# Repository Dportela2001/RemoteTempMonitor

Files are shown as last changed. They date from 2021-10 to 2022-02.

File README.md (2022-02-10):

# RemoteTempMonitor :beers:
Equipo:
 - Diego Alejandro Figueroa del Castillo
 - Danny Esteban Portela Robayo
 - Omar Andrés Cely Villate

Dispositivo embebido enfocado a monitorear y guiar al usuario en la creación de cerveza. Se pretende que el dispositivo funcione como una herramienta de ayuda que pueda facilitar la toma de temperatura, y el subsecuente control de la misma en las fáses de calentamiento y enfriamiento del mosto.

## Descripción no funcional

- Acoplarse adecuadamente al recipiente empleado.
- Comunicarse de manera inalámbrica via Wifi o bluetooth. 
- Tener una resolución de 1°C con incertidumbre de  0.5°C.
- Medir temperaturas entre: 0ºC a 120ºC. 
- Establecer conexiones a mínimo 10 m de distancia.
- Tener un tiempo de comunicación de 15s.

## Descripción funcional 

- Medir temperatura.
- Enviar la temperatura a un dispositivo móvil .
- Permitir la configuración de alarmas de temperatura.
- Disparar alarmas. 
- Mostrar temperatura en un display.

## Fases de la utilización del producto:

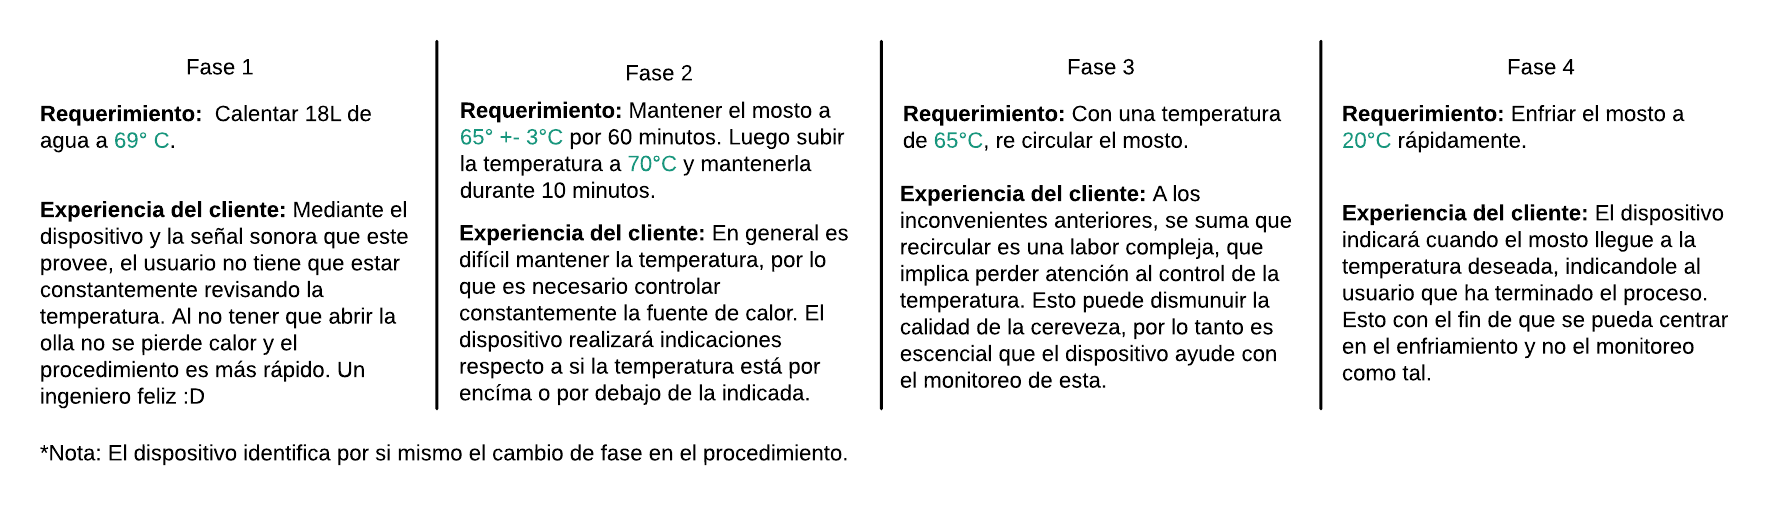
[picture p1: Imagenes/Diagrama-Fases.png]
Fases


## Diagrama de bloques de la solución

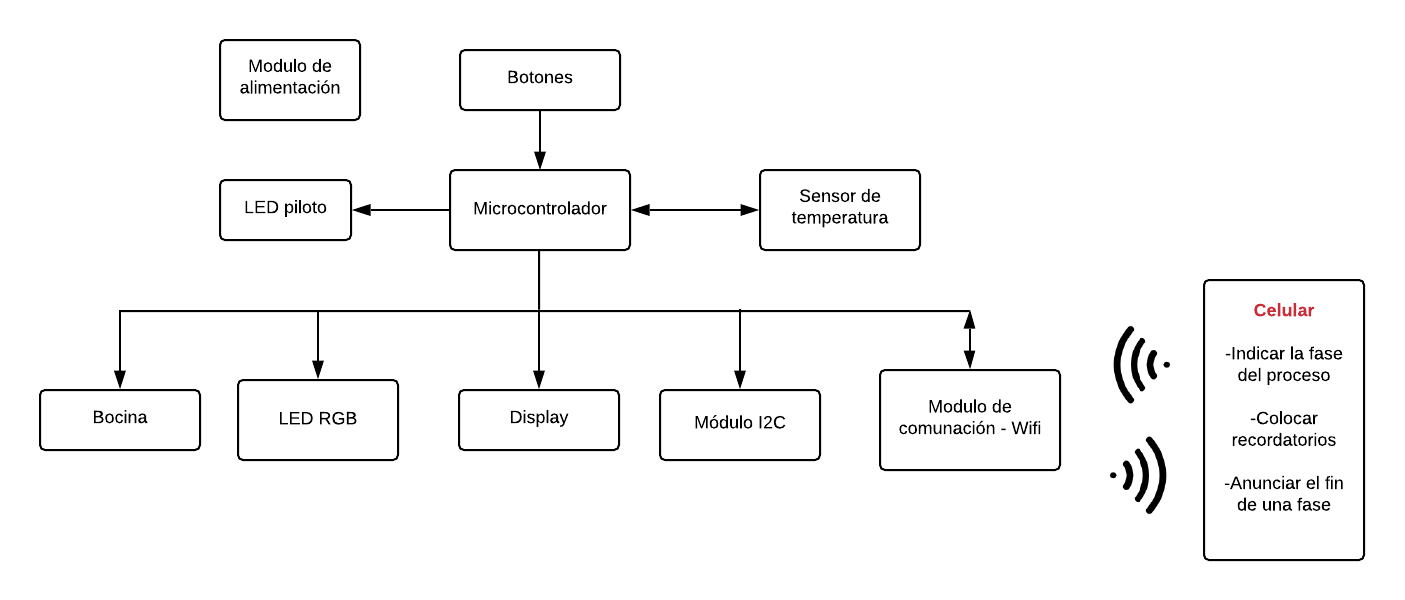
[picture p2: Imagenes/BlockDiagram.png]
Bloques


## Dispositivos a emplear :page_facing_up:
A continuación se ve una lista resumida de los elementos más importantes a utilizar, con sus respectivos precios, cantidad y tienda sugerida, para una lista más detallada de todos los componentes puede ver el excel [**Lista_componentes.xlsx**](/Lista_componentes.xlsx).

# [Diseño de la pcb](/CircuitDesign):bulb:

Para llevar a cabo el diseño del circuito embebido, se empleó el programa open source Kikad, donde todos los archivos generados se encuentran en la carpeta **CircuitDesign**, en donde se encuentran dos versiones de la placa. La primera empleando vias para conectar la cara superior con la inferior, que se ve en la carpeta **PCB_Design**. Sin embargo, debido a las limitaciones de tiempo y capacidades de realización fue necesario realizar una modificación cambiando las vias por conexiones mediante pines. Este segundo diseño se encuentra en **PCB_Design_Low_Cost**

## Zona de potencia
Como todo circuito electrónico, se requiere de una fuente de potencia para el funcionamiento del mismo. Para esto se planteó fos bloques principales, uno para la regulación de voltage que llega a la ESP32 y sus periféricos, y un bloque de carga para las baterías que alimentan el conjunto. Dichos bloques son:

<p align="center">
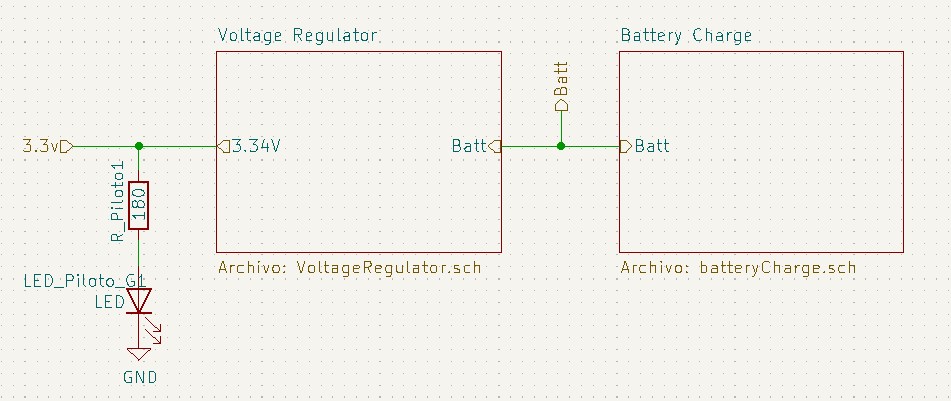
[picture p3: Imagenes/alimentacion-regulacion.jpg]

</p>
  
## Regulador de Voltaje
Dado que la tensión que entregan las baterías de Litio es de 4.2V, es necesario agregar el integrado MIC37303YME, que permite entregar la tensión deseada de 3.3v a la entrada de la ESP32. El esquemático empleado es el siguiente:

<p align="center">
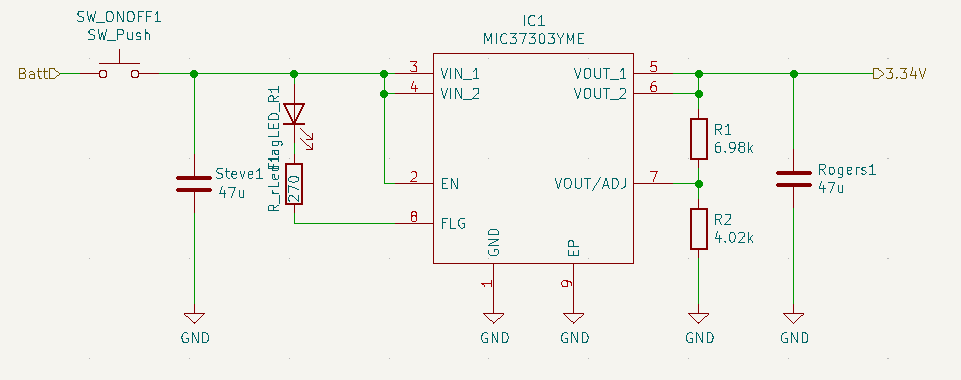
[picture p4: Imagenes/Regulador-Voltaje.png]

</p>

## Cargador de Baterías 

Evidentemente las baterias empleadas requieren ser cargadas de vez en cuando para que el sistema funcione. Por ello se agregó el integrado TP4056 con el circuito de la imagen, para realizar esta operación y así mismo proveer de leds guía de cargado y descargado.

<p align="center">
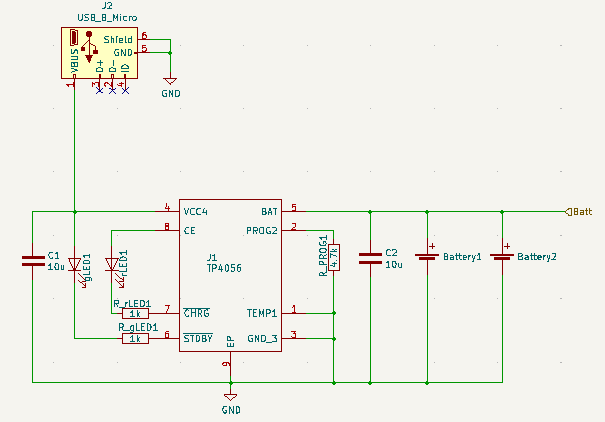
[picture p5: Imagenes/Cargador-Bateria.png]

</p>

Para conveniencia del usuario, se decidió agregar un conector tipo micro-usb B como conector para realizar la carga del dispositivo. Además cuando el dispositivo está sin carga se indicará con un led rojo como se observa a continuación:

<p align="center">
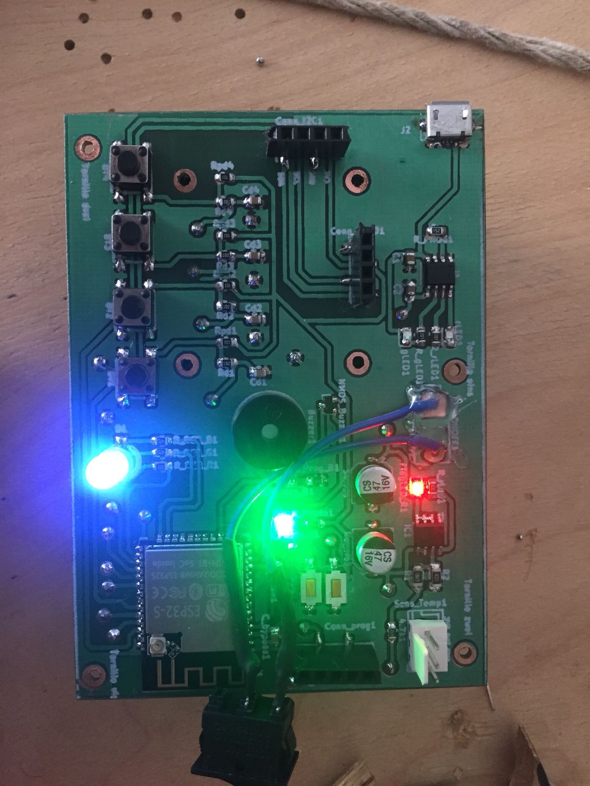
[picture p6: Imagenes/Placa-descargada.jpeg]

</p>
  
En caso de que se haya completado la carga, el indicador resultante es: 

<p align="center">
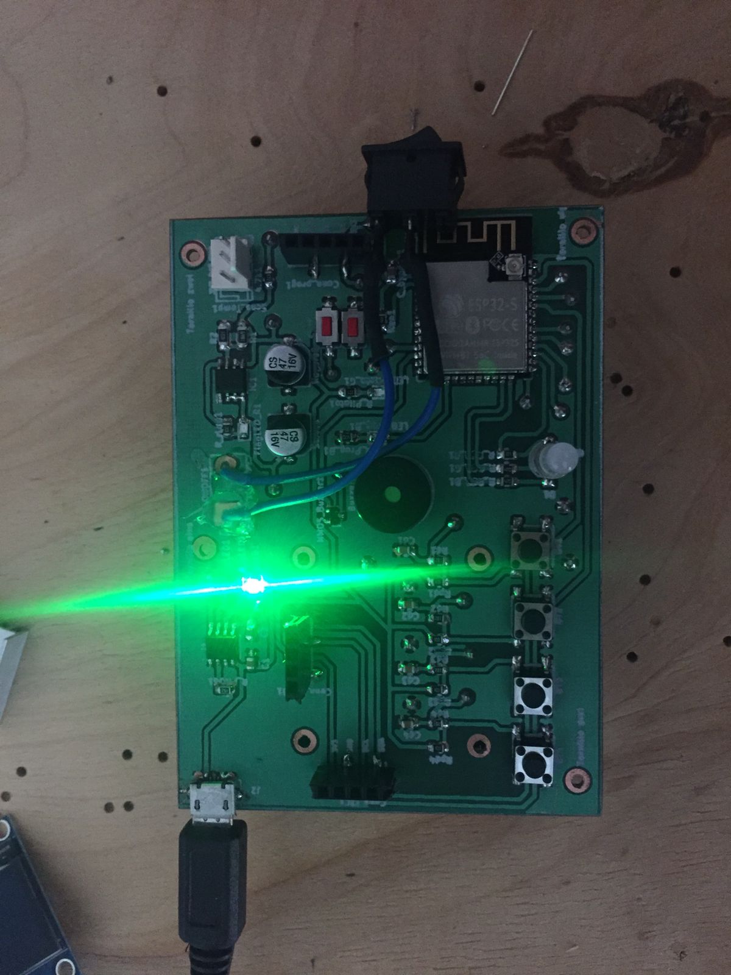
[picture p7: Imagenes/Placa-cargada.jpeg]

</p>

## Esquemático ESP32

El microprocesador empleado para el proyecto es la ESP32 standalone, que posee una flexibilidad y robustez más que suficiente para los propócitos del mismo. Es posible emplear toda la gama de pines GPIO dependiendo de la necesidad, por ejemplo para lectura o escritura. El esquemático resultante es:

<p align="center">
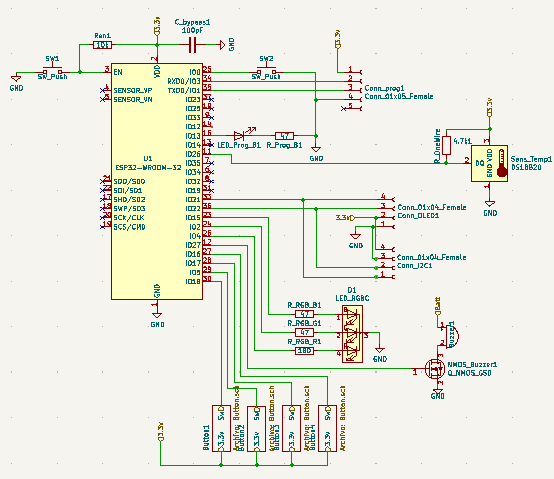
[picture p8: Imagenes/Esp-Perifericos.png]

</p>

Es posible entonces realizar el diseño de la PCB y el ruteo de los caminos  para generar los archivos gerber y enviarlos a impresión en un local dedicado a esta labor. El sieño obtenido finalmente después de añadir además las conexiones entre capas es:

<p align="center">
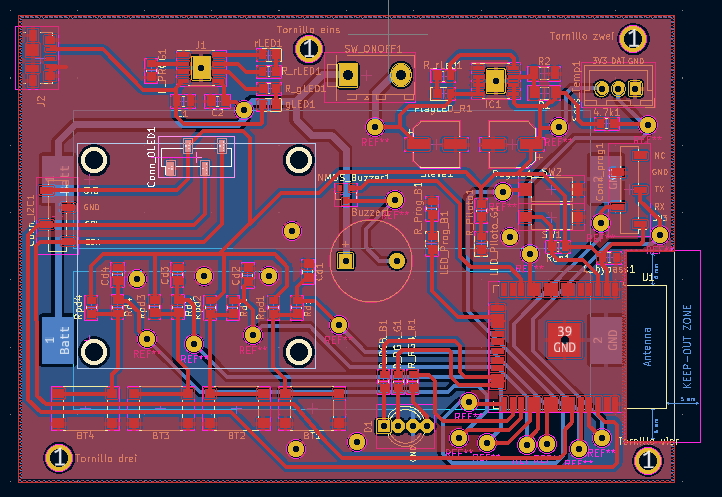
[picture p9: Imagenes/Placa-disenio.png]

</p>

# [Software del dispositivo](/Micropython):snake: 

Para poder programar el microprocesador ESP32 se optó por usar el lenguaje **MicroPython**, por su facilidad de sintaxis, versatilidad y cantidad de librerias disponibles para facilitar el proceso de codificación. Algunas de las librerías empleadas son:

- SH1106 (librería para controlar la pantalla OLED, extraida de: https://github.com/robert-hh/SH1106)
- DS18B20 (librería para controlar la sonda de temperatura, ya presente en Micropython)

Para ver en detalle el código empleado para el funcionamiento del termómetro se puede revisar la carpeta **Micropython** en la rama principal.
Además, se empleó el programa _Mu_ para escribir y subir el código de Micropython directamente a la memoria del ESP32. Otra ventaja de este lenguaje se hace evidente en cuanto a que su subida es veloz al microprocesador, ya que el proceso de compilado del colido ocurre precisamente en este.

## Distintas instancias del programa del proyecto

El programa diseñado para el dispositivo posee distintas instancias tanto de configuración como de funcionamiento, que se encuentran en las siguientes imagenes: 
<table>
  <tr>
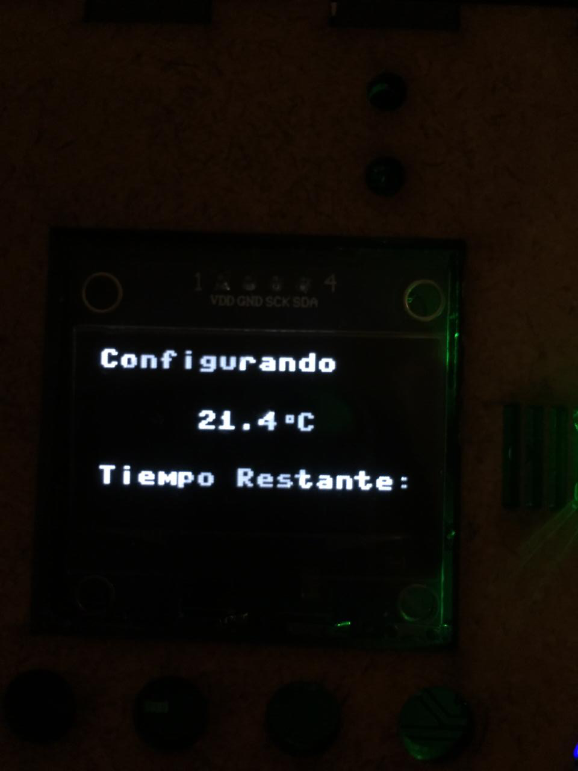
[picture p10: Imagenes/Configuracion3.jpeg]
      <td></td>
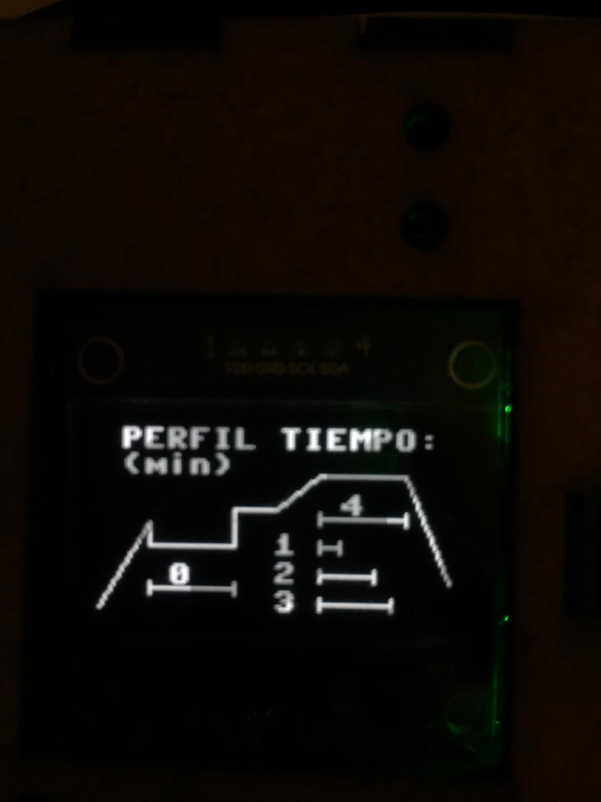
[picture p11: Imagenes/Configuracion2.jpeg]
      <td></td>
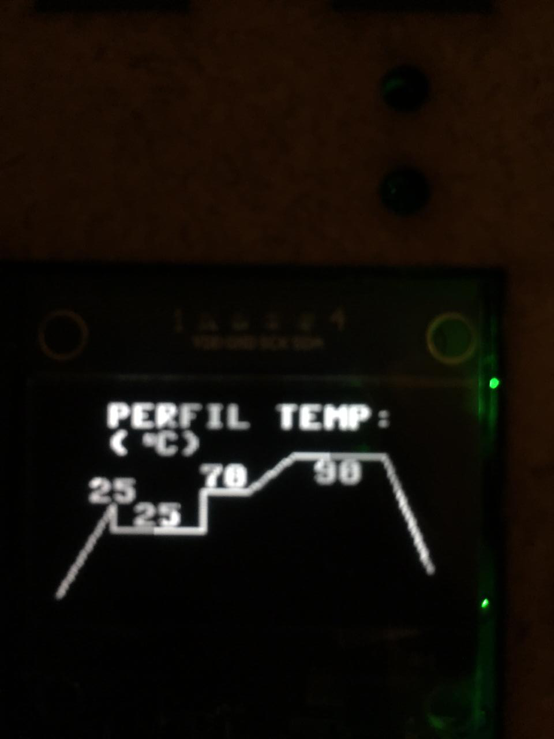
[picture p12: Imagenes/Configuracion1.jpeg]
      <td></td>
   </tr>
</table>

## [Conexión web del dispositivo](/Front-Remotetemp):computer:

Se pretendía realizar la conexión del termómetro con un dispositvo externo con un celular o computadora, con el fin de poder controlar de forma remota las distintas opciones que este ofrece. Sin embargo debido a las limitaciones de tiempo y errores al momento de generar la pagina montada en el servidor, no fue posible terminar de generar esta funcionalidad en el dispositivo. Más si se llego a producir el Front-end de esta parte, la cual se encuentra en la branch **Front-RemoteTemp**, que incluye el archivo _html_, _css_ y _javascrip_. La página diseñada es:

<p align="center">
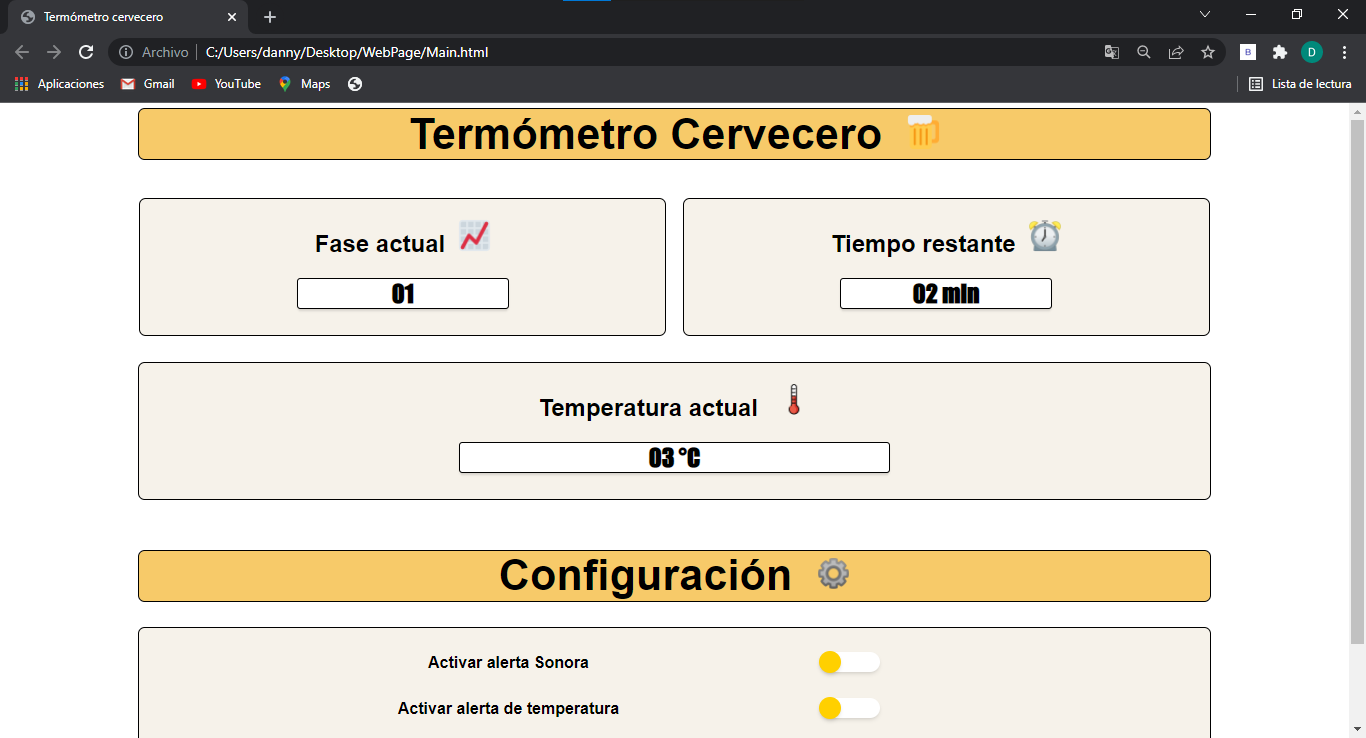
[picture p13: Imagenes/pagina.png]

</p>

## [Diseño de caja](/Box-Design) :package:

Con el fin de realizar un empaquetado para el termómetro, se realizó el diseño de una caja en madera con corte laser mediante el programa de CorelDraw. El objetivo es que esta  proteja el circuito del termómetro como tal, así como proveerle una mejor apariencia estética. 
Para el diseño se emplearon las medidas tomadas directamente del diseño obtenido de la pcb en Kicad:

<p align="center">
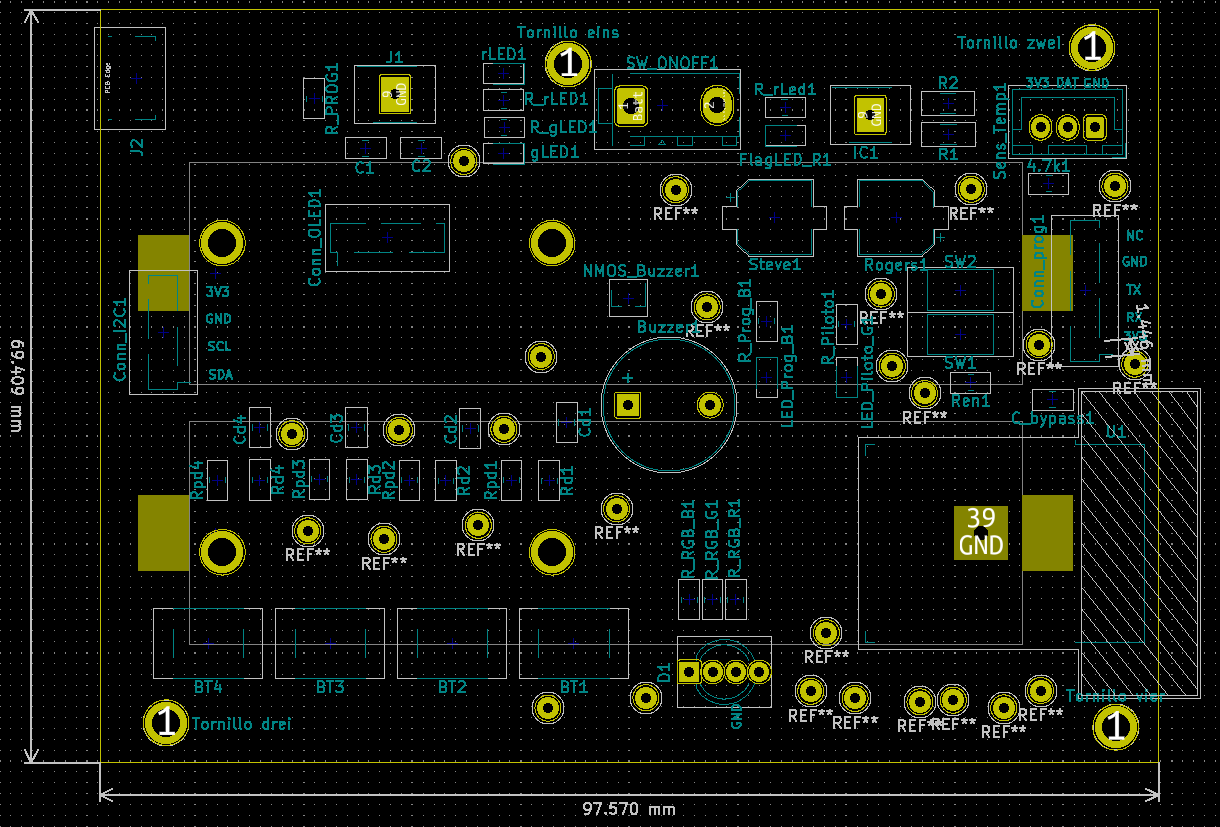
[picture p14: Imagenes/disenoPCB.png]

</p>

Entonces se planea el diseño de tal forma de que haya cierta tolerancia a los tamaños reales de la plata. Se tienen en cuenta elementos que deben ser visibles al usuario como:

- Pantalla de interacción.
- Botonera.
- Puerto de carga USB.
- Led de indicación de bateria baja.
- Led de indicación de carga completa.
- Rejilla para el buzzer.

El resultado del diseño se encuentra en la sección **Box-Design**, donde se encuentran tanto los archivos generados en formatos .pdf y .svg (archivo de gráficos escalables), como el archivo original para ser abierto en el programa CorelDraw. La previsualización resulta:

<p align="center">
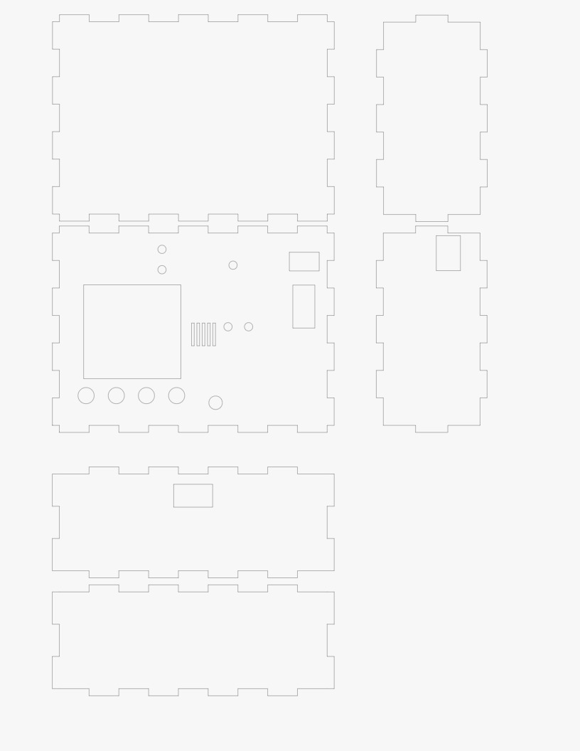
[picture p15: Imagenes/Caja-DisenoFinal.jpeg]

</p>

## Dispositivo resultante 

Después de realizar la soldadura de los elementos en el circuito impreso, se añadieron así mismo los periféricos como la pantalla OLED, el Buzzer y la sonda de temperatura. El dispositivo físico final es el que se ve a continuación:

<p align="center">
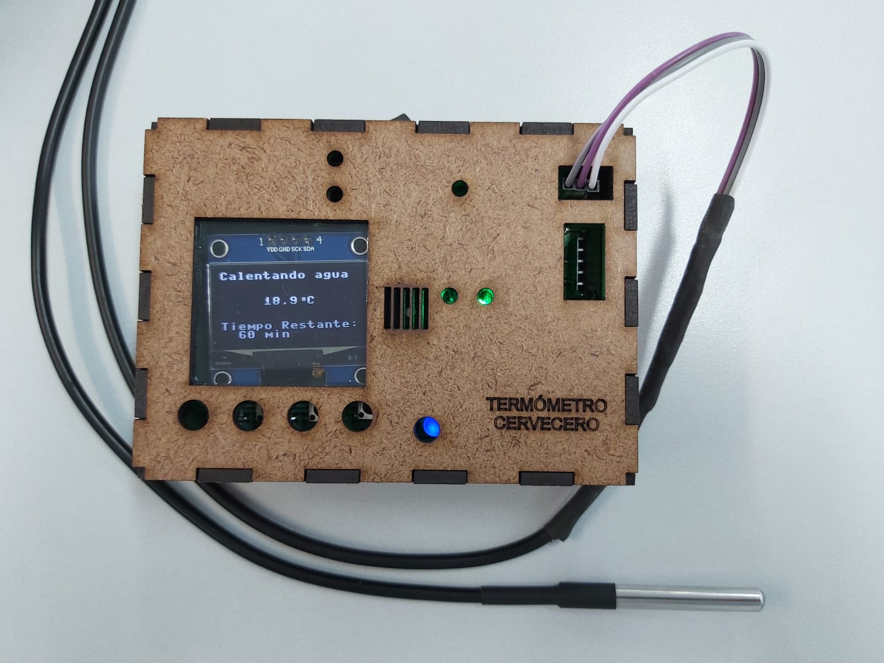
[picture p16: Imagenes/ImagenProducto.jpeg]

</p>

El layout de los botones y demás periféricos del dispositivo es:

<p align="center">
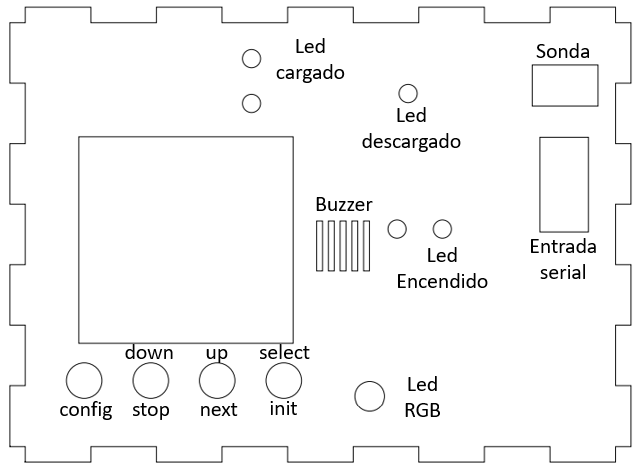
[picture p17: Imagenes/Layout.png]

</p>

## Conclusiones del proyecto :chart_with_upwards_trend:

- Una correcta planeación de los objetivos del proyecto permite la delimitación del mismo, haciendo que su realización sea más posible.
- El diseño PCB para un sistema embebido requiere de diversas consideraciones, tanto físicas y de funcionamiento como de estandares de producción, para que puedan llegar a ser producidas sin problemas. Estas consideraciones incluyen temas como tamaños de vías, anchos de pista, tamaños de los taladros, grosor del FR4, etc.

## Errores cometidos durante el desarrollo
- Al momento de colocar los pines para colocar la pantalla OLED en el diseño de la placa, se cometió el error de invertir el orden de los pines GND y VDC dado que nos guiamos por la imagen que colocaba el vendedor en su pagina, que era distinta al producto vendido. Esto produjo que la primera parantalla empleada se quemara ya que estaba conectada de manera incorrecta, por lo que fue necesario conseguir otra de estas y realizar una reconexión de manera externa con los sockets para los pines de la pantalla.
- Los tiempos de manufactura de la placa no fueron los adecuados, por lo que fue imposible el solicitar fabricar las PCB en una empreza extrangera China como JLCPCB, PCBWAY, etc. Esto causo que fuera necesario re inventar la placa para no usar vias entre capas, dado que las empresas locales que prestaban estos servicios, lo realizaban a un costo muy alto. Por lo tanto fue necesario recrear la placa de forma en que se omitieran las vías.
- La propia calidad de la placa complicó el hecho de soldar el conector micro-usb, por lo que posteriormente causó una ruptura en el mismo.
- Debido a que no se consiguió desplegar la pagina web en los servidores de _Heroku_ no fue posible crear la lógica de Back-end para poder controlar el dispositivo de forma remota.

# Videos de prueba de funcionamiento
https://user-images.githubusercontent.com/85375999/153422038-b12df55a-1030-432a-aa8d-7aa34144cbf2.mp4

https://user-images.githubusercontent.com/85375999/153430220-765915c4-69fb-4bd9-bc61-4cbe634cb242.mp4

https://user-images.githubusercontent.com/85375999/153430800-7f2c6cfe-6833-4663-b4ba-db0c7dcf290a.mp4

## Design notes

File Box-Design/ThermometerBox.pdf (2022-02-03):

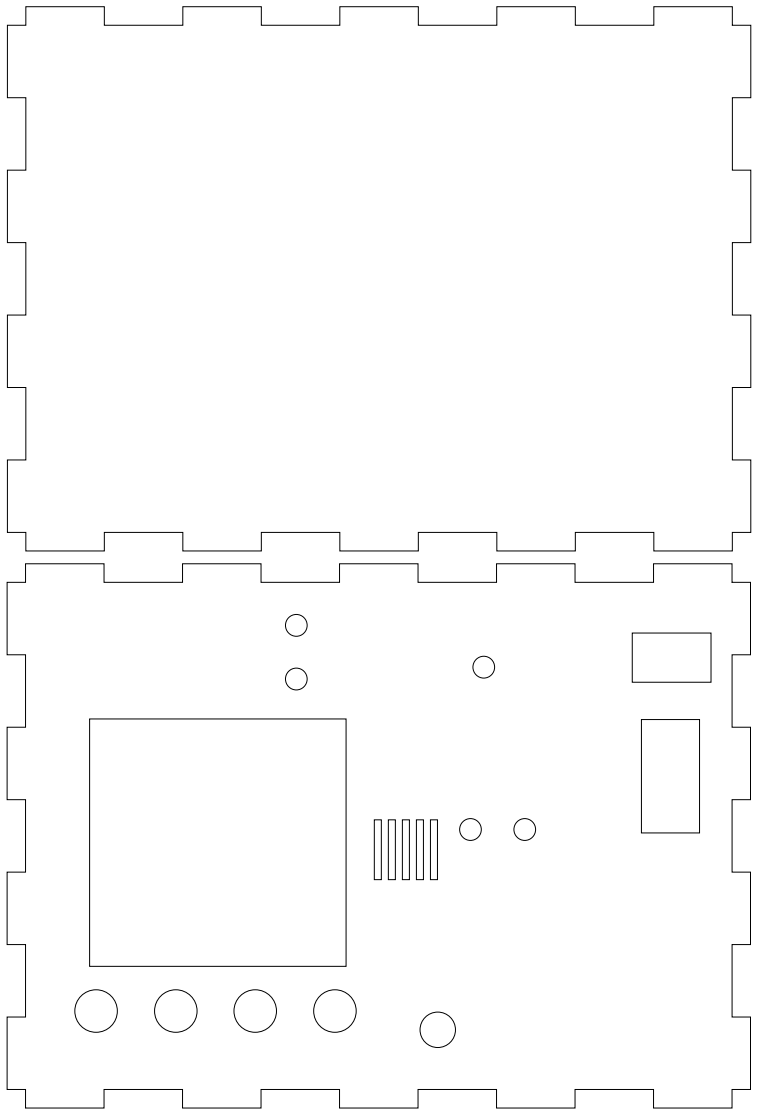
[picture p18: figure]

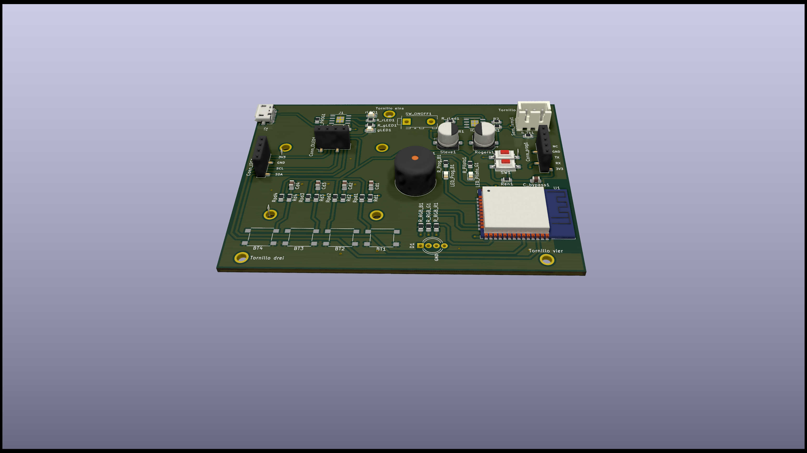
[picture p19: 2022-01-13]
CircuitDesign/PCB_Design/PCB_Design.png

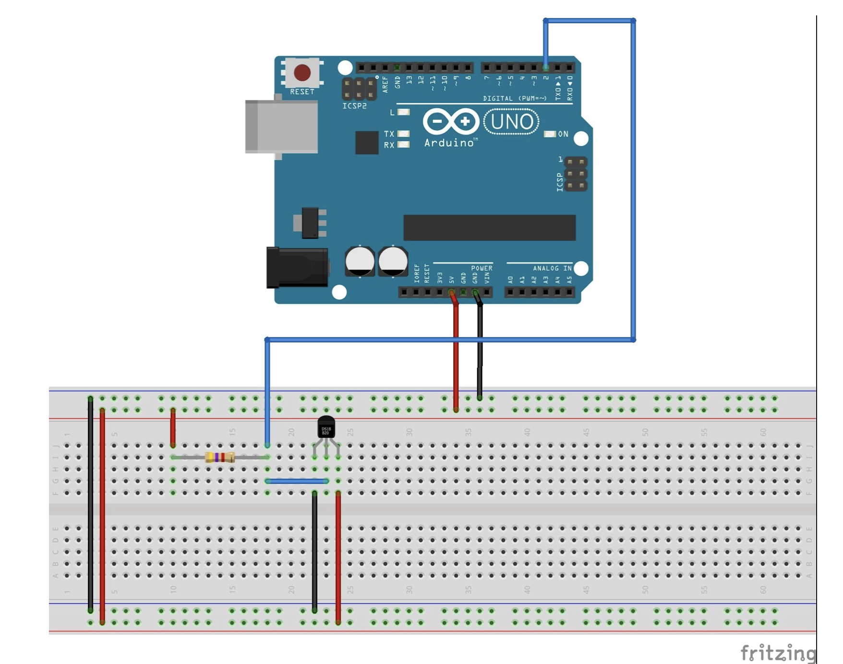
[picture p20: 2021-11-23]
CircuitDesign/Esquematicos/Esquematico_DS18B20.png

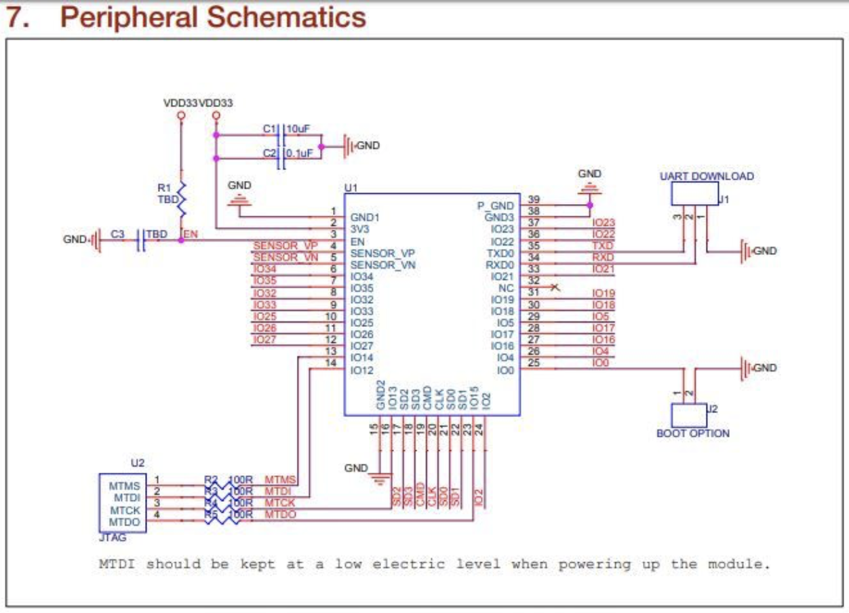
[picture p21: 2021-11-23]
CircuitDesign/Esquematicos/Esquematico_esp32_stanalone.png

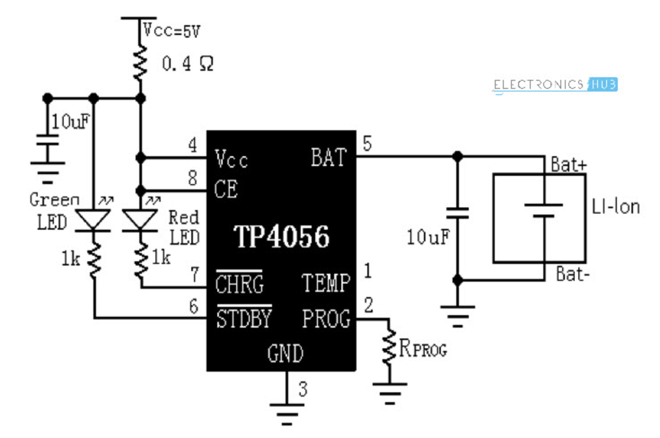
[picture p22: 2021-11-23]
CircuitDesign/Esquematicos/Esquematico_TP4056.png

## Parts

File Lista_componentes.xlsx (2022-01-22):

Item | Qty | Reference(s) | Value | Compañia | estado compra | precio unidad | cantidad compra | quien compró | Total | Elementos de sobra | Precio de elementos sobrantes
1 | 2 | R_OneWire R_PROG1 | 4.7k1 | Sigma |  | 47.6 | 10 | Diego | 476 | 8 | 380.8
2 | 2 | Battery holder, Battery holder | Battery_Cell | Mactrónica |  | 5000 | 2 | Diego | 10000 | 0 | 0
3 | 2 | Battery1, Battery2 | Battery_Cell | Mercado Libre |  | 10400 | 2 | Omar | 20800 | 0 | 0
4 | 4 | BT1, BT2, BT3, BT4 | SW_Push | Mactrónica |  | 375 | 4 | Danny | 1500 | 0 | 0
5 | 1 | Buzzer1 | Buzzer | Mactrónica |  | 2000 | 1 | Danny | 2000 | 0 | 0
6 | 2 | C1, C2 | 10u | Sigma |  | 238 | 4 | Diego | 952 | 2 | 476
7 | 4 | Cd1, Cd2, Cd3, Cd4 | 0.1u | Sigma |  | 119 | 6 | Diego | 714 | 2 | 238
8 | 1 | Conn_I2C1 | Conn_01x04_Female | ----- |  | 0 | 1 | Diego | 0 | 0 | 0
9 | 1 | Pantalla OLED | oled 1.3" | Mactrónica |  | 25000 | 1 | Danny | 25000 | 0 | 0
10 | 1 | Conn_OLED1 | Conn_01x04_Female | ----- |  | 0 | 1 | Diego | 0 | 0 | 0
11 | 1 | Conn_prog1 | Conn_01x05_Female | ----- |  | 0 | 1 | Diego | 0 | 0 | 0
12 | 1 | D1 | LED_RGBC | Mactrónica |  | 1000 | 1 | Diego | 1000 | 0 | 0
13 | 5 | FlagLED_R1, gLED1, LED_Piloto_G1, LED_Prog_B1, rLED1 | LED | Sigma |  | 238 | 8 | Diego | 1904 | 3 | 714
14 | 1 | IC1 | MIC37303YME | Sigma |  | 7735 | 1 | Diego | 7735 | 0 | 0
15 | 1 | J1 | TP4056 | Sigma |  | 2142 | 1 | Diego | 2142 | 0 | 0
16 | 1 | J2 | USB-b micro | centro |  | 1000 | 1 | Omar | 1000 | 0 | 0
17 | 1 | NMOS_Buzzer1 | NMOS | Sigma |  | 476 | 2 | Diego | 952 | 1 | 476
18 | 1 | R1 | 6.98k | Sigma |  | 59.5 | 10 | Diego | 595 | 9 | 535.5
19 | 1 | R2 | 4.02k | Sigma |  | 59.5 | 10 | Diego | 595 | 9 | 535.5
20 | 6 | R_gLED1, R_rLED1, Rd1, Rd2, Rd3, Rd4 | 1k | Sigma |  | 47.6 | 10 | Diego | 476 | 4 | 190.4
21 | 2 | R_Piloto1, R_RGB_R1 | 220 | Sigma |  | 47.6 | 10 | Diego | 476 | 8 | 380.8
22 | 3 | R_Prog_B1, R_RGB_B1, R_RGB_G1 | 47 | Sigma |  | 47.6 | 10 | Diego | 476 | 7 | 333.2
23 | 1 | R_rLed1 | 300 | Sigma |  | 47.6 | 10 | Diego | 476 | 9 | 428.4
24 | 5 | Ren1, Rpd1, Rpd2, Rpd3, Rpd4 | 10k | Sigma |  | 47.6 | 10 | Diego | 476 | 5 | 238
25 | 2 | Rogers1, Steve1 | 47u | Sigma |  | 357 | 3 | Diego | 1071 | 1 | 357
26 | 1 | conn Sens_Temp1 | JST | centro |  | 0 | 1 | Omar | 0 | 0 | 0
27 | 1 | Sens_Temp1 | DS18B20 | Sigma |  | 10948 | 1 | Diego | 10948 | 0 | 0
28 | 2 | SW1, SW2 | SW_Push | Sigma |  | 357 | 2 | Diego | 714 | 0 | 0
29 | 1 | SW_ONOFF1 | SW_Push | Mactrónica |  | 1500 | 1 | Danny | 1500 | 0 | 0
30 | 1 | U1 | ESP32-WROOM-32 | Mactrónica |  | 19000 | 1 | Diego | 19000 | 0 | 0
31 | 1 | Envio Sigma |  | Sigma |  | 11186 | 1 | Diego | 11186 | 0 | 0
32 | 1 | PCB |  | Contacto PCB |  | 45000 | 1 | Diego | 45000 | 0 | 0
33 | 1 | Envio mercado libre |  | Mercado Libre |  | 15000 | 1 | Omar | 15000 | 0 | 0
 |  |  |  |  |  |  |  |  | 184164 |  | 5283.6
 |  |  | Compras por persona |  | Saldo |  | Compras por tienda
 |  |  | Diego | 117364 | 55976 |  | Sigma | 42364
 |  |  | Omar | 36800 | -24588 |  | Mactrónica | 60000
 |  |  | Danny | 30000 | -31388 |  | Mercado Libre | 35800
 |  |  |  | 184164 | 0 |  | Contacto PCB | 45000
 |  |  |  |  |  |  | centro | 1000
 |  |  |  |  |  |  |  | 184164

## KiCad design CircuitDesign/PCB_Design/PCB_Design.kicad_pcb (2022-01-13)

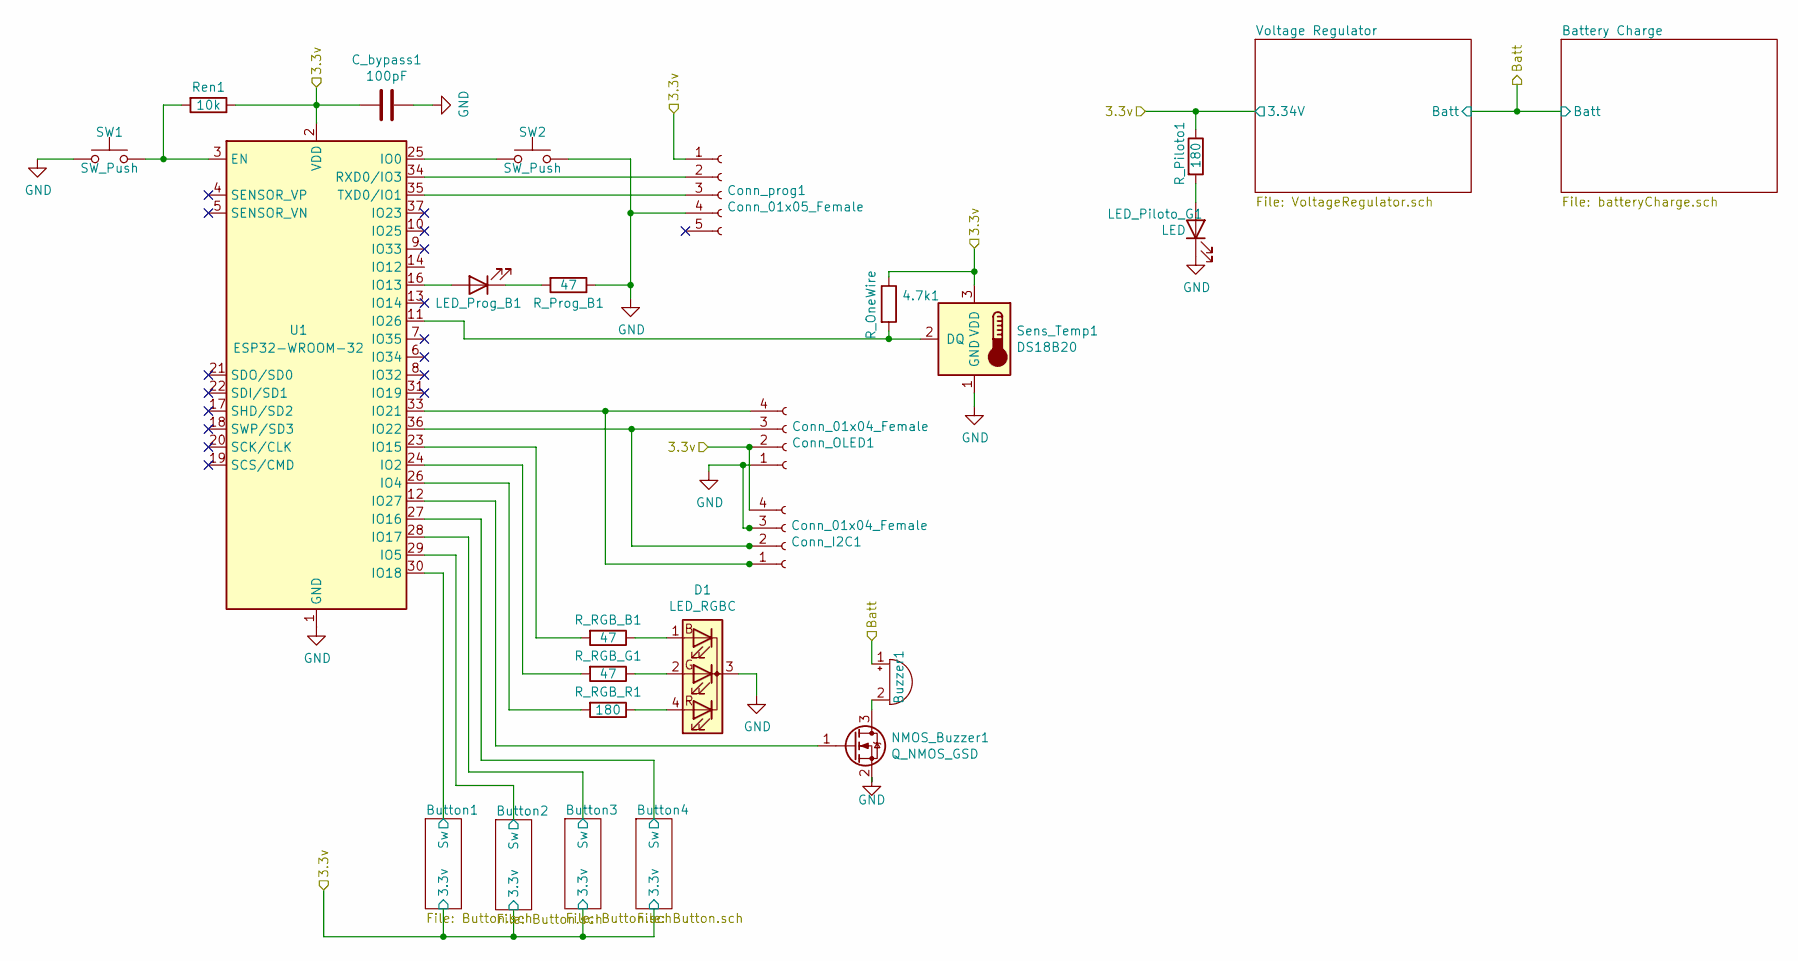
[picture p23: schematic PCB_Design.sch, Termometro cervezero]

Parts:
4.7k1: R_OneWire; R_0805_2012Metric_Pad1.20x1.40mm_HandSolder
Buzzer1: Buzzer; Buzzer_12x9.5RM7.6
C_bypass1: 100pF; C_0805_2012Metric_Pad1.18x1.45mm_HandSolder
Conn_I2C1: Conn_01x04_Female; PinSocket_1x04_P2.54mm_Vertical_SMD_Pin1Left
Conn_OLED1: Conn_01x04_Female; PinSocket_1x04_P2.54mm_Vertical_SMD_Pin1Left
Conn_prog1: Conn_01x05_Female; PinSocket_1x05_P2.54mm_Vertical_SMD_Pin1Left
D1: LED_RGBC; LED_D5.0mm-4_RGB_Wide_Pins
LED_Piloto_G1: LED; LED_0805_2012Metric_Pad1.15x1.40mm_HandSolder
LED_Prog_B1: LED; LED_0805_2012Metric_Pad1.15x1.40mm_HandSolder
NMOS_Buzzer1: Q_NMOS_GSD; SOT-23
R_Piloto1: 180; R_0805_2012Metric_Pad1.20x1.40mm_HandSolder
R_Prog_B1: 47; R_0805_2012Metric_Pad1.20x1.40mm_HandSolder
R_RGB_B1: 47; R_0805_2012Metric_Pad1.20x1.40mm_HandSolder
R_RGB_G1: 47; R_0805_2012Metric_Pad1.20x1.40mm_HandSolder
R_RGB_R1: 180; R_0805_2012Metric_Pad1.20x1.40mm_HandSolder
Ren1: 10k; R_0805_2012Metric_Pad1.20x1.40mm_HandSolder
SW1, SW2: SW_Push; SW_SPST_CK_RS282G05A3
Sens_Temp1: DS18B20; JST_XH_B3B-XH-A_1x03_P2.50mm_Vertical
U1: ESP32-WROOM-32

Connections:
/3.3v: 4.7k1.1, C_bypass1.2, Conn_I2C1.4, Conn_OLED1.2, Conn_prog1.1, R_Piloto1.1, Ren1.1, Sens_Temp1.3 (VDD), U1.2 (VDD); also elsewhere on the board
/Batt: Buzzer1.1 (-); also elsewhere on the board
/Button1/Sw: U1.30 (IO18); also elsewhere on the board
/Button2 /Sw: U1.29 (IO5); also elsewhere on the board
/Button3/Sw: U1.28 (IO17); also elsewhere on the board
/Button4/Sw: U1.27 (IO16); also elsewhere on the board
GND: C_bypass1.1, Conn_I2C1.3, Conn_OLED1.1, Conn_prog1.4, D1.3 (K), LED_Piloto_G1.1 (K), NMOS_Buzzer1.2 (S), R_Prog_B1.1, SW1.1, SW2.2, Sens_Temp1.1 (GND), U1.1 (GND), U1.15 (GND), U1.38 (GND), U1.39 (GND); also elsewhere on the board
unnamed: 4.7k1.2, Sens_Temp1.2 (DQ), U1.11 (IO26)
unnamed: Buzzer1.2 (+), NMOS_Buzzer1.3 (D)
unnamed: Conn_I2C1.1, Conn_OLED1.4, U1.33 (IO21)
unnamed: Conn_I2C1.2, Conn_OLED1.3, U1.36 (IO22)
unnamed: Conn_prog1.2, U1.34 (RXD0/IO3)
unnamed: Conn_prog1.3, U1.35 (TXD0/IO1)
unnamed: D1.1 (BA), R_RGB_B1.1
unnamed: D1.2 (GA), R_RGB_G1.1
unnamed: D1.4 (RA), R_RGB_R1.1
unnamed: LED_Piloto_G1.2 (A), R_Piloto1.2
unnamed: LED_Prog_B1.1 (K), R_Prog_B1.2
unnamed: LED_Prog_B1.2 (A), U1.16 (IO13)
unnamed: NMOS_Buzzer1.1 (G), U1.12 (IO27)
unnamed: R_RGB_B1.2, U1.23 (IO15)
unnamed: R_RGB_G1.2, U1.24 (IO2)
unnamed: R_RGB_R1.2, U1.26 (IO4)
unnamed: Ren1.2, SW1.2, U1.3 (EN)
unnamed: SW2.1, U1.25 (IO0)

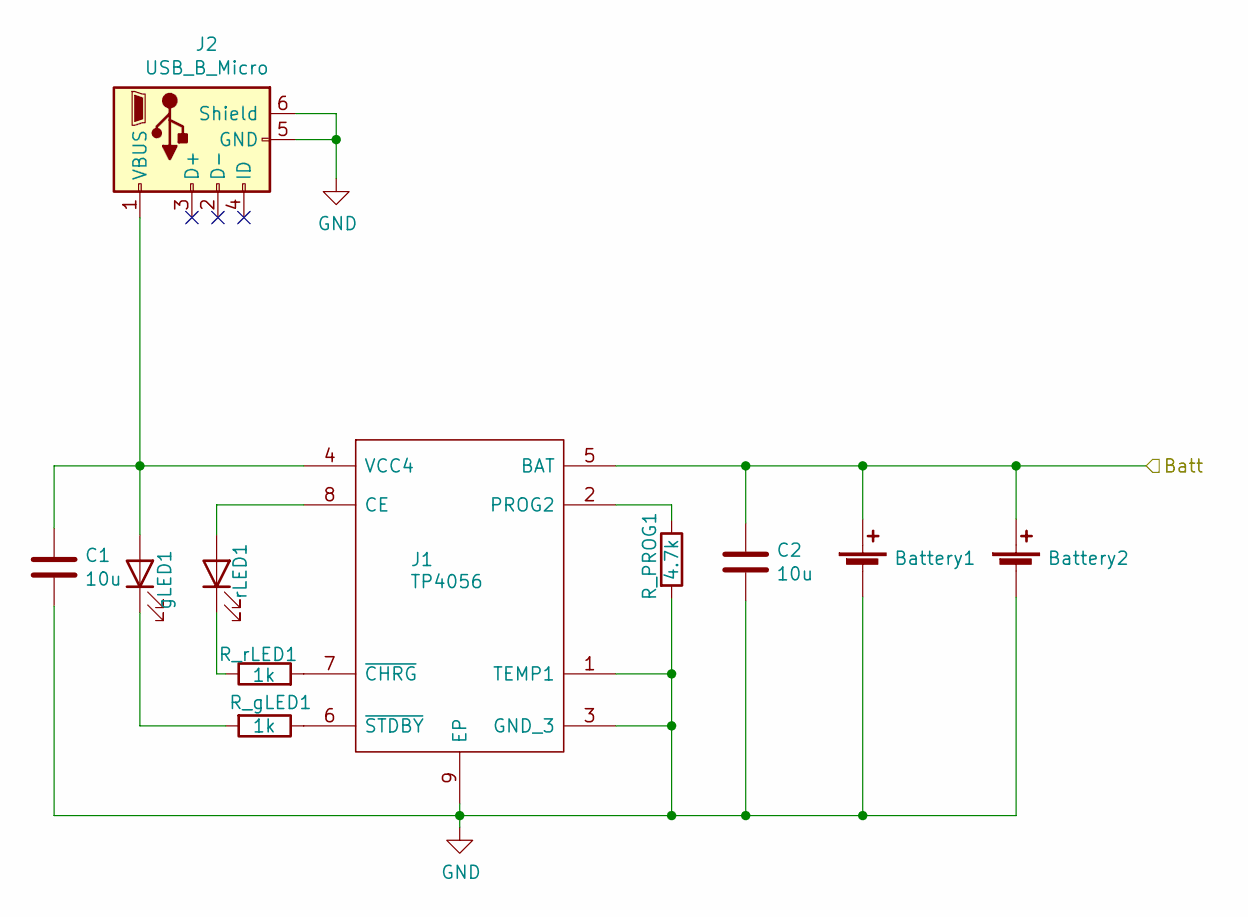
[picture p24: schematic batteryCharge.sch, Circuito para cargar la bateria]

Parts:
Battery1, Battery2: Battery_Cell; BatteryHolder_MPD_BH-18650-PC2
C1, C2: 10u; C_0805_2012Metric_Pad1.18x1.45mm_HandSolder
J1: TP4056; SOIC-8-1EP_3.9x4.9mm_P1.27mm_EP2.514x3.2mm; Manufacturer_Part_Number TP4056
J2: USB_B_Micro; USB_Micro-B_Molex_47346-0001
R_PROG1: 4.7k; R_0805_2012Metric_Pad1.20x1.40mm_HandSolder
R_gLED1: 1k; R_0805_2012Metric_Pad1.20x1.40mm_HandSolder
R_rLED1: 1k; R_0805_2012Metric_Pad1.20x1.40mm_HandSolder
gLED1: LED; LED_0805_2012Metric_Pad1.15x1.40mm_HandSolder
rLED1: LED; LED_0805_2012Metric_Pad1.15x1.40mm_HandSolder

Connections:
/Batt: Battery1.1 (+), Battery2.1 (+), C2.1, J1.5 (BAT); also elsewhere on the board
GND: Battery1.2 (-), Battery2.2 (-), C1.2, C2.2, J1.1 (TEMP1), J1.3 (GND_3), J1.9 (EP), J2.5 (GND), J2.6 (Shield), R_PROG1.2; also elsewhere on the board
unnamed: C1.1, J1.4 (VCC4), J2.1 (VBUS), gLED1.2 (A)
unnamed: J1.2 (PROG2), R_PROG1.1
unnamed: J1.6 (~STDBY), R_gLED1.1
unnamed: J1.7 (~CHRG), R_rLED1.2
unnamed: J1.8 (CE), rLED1.2 (A)
unnamed: R_gLED1.2, gLED1.1 (K)
unnamed: R_rLED1.1, rLED1.1 (K)

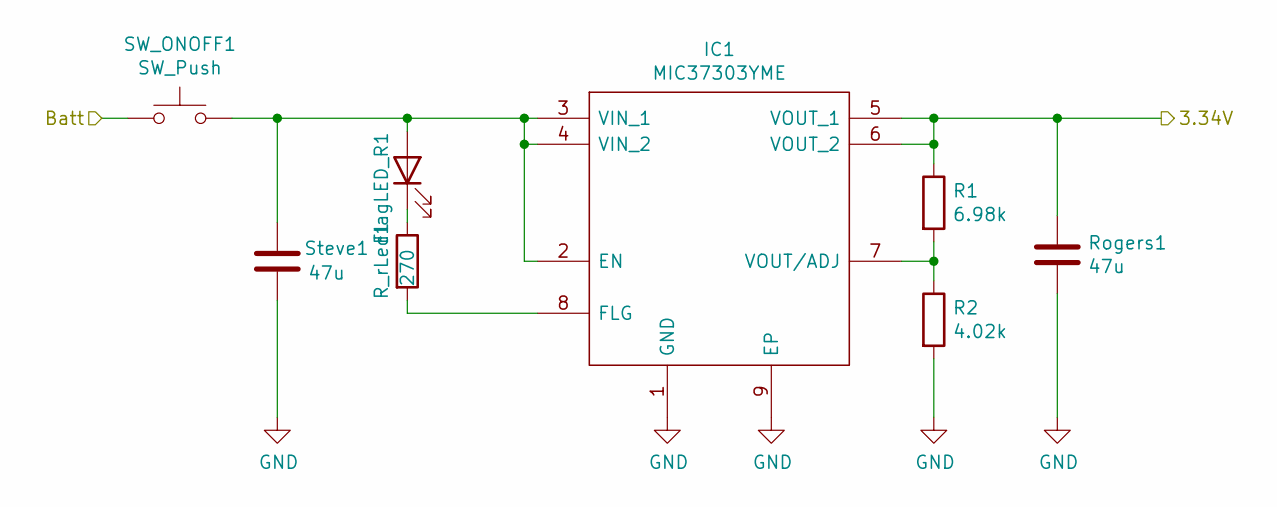
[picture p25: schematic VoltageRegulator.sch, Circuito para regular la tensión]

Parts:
FlagLED_R1: LED; LED_0805_2012Metric_Pad1.15x1.40mm_HandSolder
IC: MIC37303YME; SOIC-8-1EP_3.9x4.9mm_P1.27mm_EP2.514x3.2mm; Manufacturer_Part_Number MIC37303YME-TR; Mouser Part Number 998-MIC37303YMETR
R1: 6.98k; R_1206_3216Metric_Pad1.30x1.75mm_HandSolder
R2: 4.02k; R_1206_3216Metric_Pad1.30x1.75mm_HandSolder
R_rLed1: 270; R_0805_2012Metric_Pad1.20x1.40mm_HandSolder
Rogers1: 47u; CP_Elec_6.3x5.9
SW_ONOFF1: SW_Push; TE_MATE-N-LOK_1-770866-x_1x02_P4.14mm_Vertical
Steve1: 47u; CP_Elec_6.3x5.9

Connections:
/3.3v: R1.1, Rogers1.1; also elsewhere on the board
/Batt: SW_ONOFF1.1; also elsewhere on the board
GND: R2.2, Rogers1.2, Steve1.2; also elsewhere on the board
unnamed: FlagLED_R1.1 (K), R_rLed1.1
unnamed 23: FlagLED_R1.2 (A), SW_ONOFF1.2, Steve1.1; also elsewhere on the board
unnamed 24: R1.2, R2.1; also elsewhere on the board
unnamed 25: R_rLed1.2; also elsewhere on the board

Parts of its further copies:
IC1: MIC37303YME; SOIC-8-1EP_3.9x4.9mm_P1.27mm_EP2.514x3.2mm; Manufacturer_Part_Number MIC37303YME-TR; Mouser Part Number 998-MIC37303YMETR

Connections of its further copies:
/3.3v: IC1.5 (VOUT_1), IC1.6 (VOUT_2); also elsewhere on the board
GND: IC1.1 (GND), IC1.9 (EP); also elsewhere on the board
unnamed 23: IC1.2 (EN), IC1.3 (VIN_1), IC1.4 (VIN_2); also elsewhere on the board
unnamed 24: IC1.7 (VOUT/ADJ); also elsewhere on the board
unnamed 25: IC1.8 (FLG); also elsewhere on the board

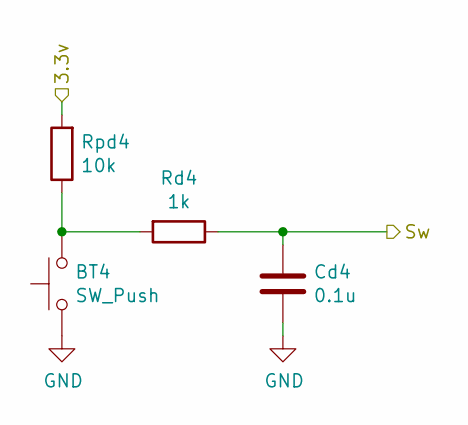
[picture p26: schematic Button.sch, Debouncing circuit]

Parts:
BT1: SW_Push; SW_Push_1P1T_NO_6x6mm_H9.5mm
Cd1: 0.1u; C_0805_2012Metric_Pad1.18x1.45mm_HandSolder
Rd1: 1k; R_0805_2012Metric_Pad1.20x1.40mm_HandSolder
Rpd1: 10k; R_0805_2012Metric_Pad1.20x1.40mm_HandSolder

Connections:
/3.3v: Rpd1.2; also elsewhere on the board
/Button1/Sw: Cd1.2, Rd1.1; also elsewhere on the board
GND: BT1.1, Cd1.1; also elsewhere on the board
unnamed: BT1.2, Rd1.2, Rpd1.1

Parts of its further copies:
BT2, BT3, BT4: SW_Push; SW_Push_1P1T_NO_6x6mm_H9.5mm
Cd2, Cd3, Cd4: 0.1u; C_0805_2012Metric_Pad1.18x1.45mm_HandSolder
Rd2, Rd3, Rd4: 1k; R_0805_2012Metric_Pad1.20x1.40mm_HandSolder
Rpd2, Rpd3, Rpd4: 10k; R_0805_2012Metric_Pad1.20x1.40mm_HandSolder

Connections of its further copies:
/3.3v: Rpd2.2, Rpd3.2, Rpd4.2; also elsewhere on the board
/Button2 /Sw: Cd2.2, Rd2.1; also elsewhere on the board
/Button3/Sw: Cd3.2, Rd3.1; also elsewhere on the board
/Button4/Sw: Cd4.2, Rd4.1; also elsewhere on the board
GND: BT2.1, BT3.1, BT4.1, Cd2.1, Cd3.1, Cd4.1; also elsewhere on the board
unnamed: BT2.2, Rd2.2, Rpd2.1
unnamed: BT3.2, Rd3.2, Rpd3.1
unnamed: BT4.2, Rd4.2, Rpd4.1

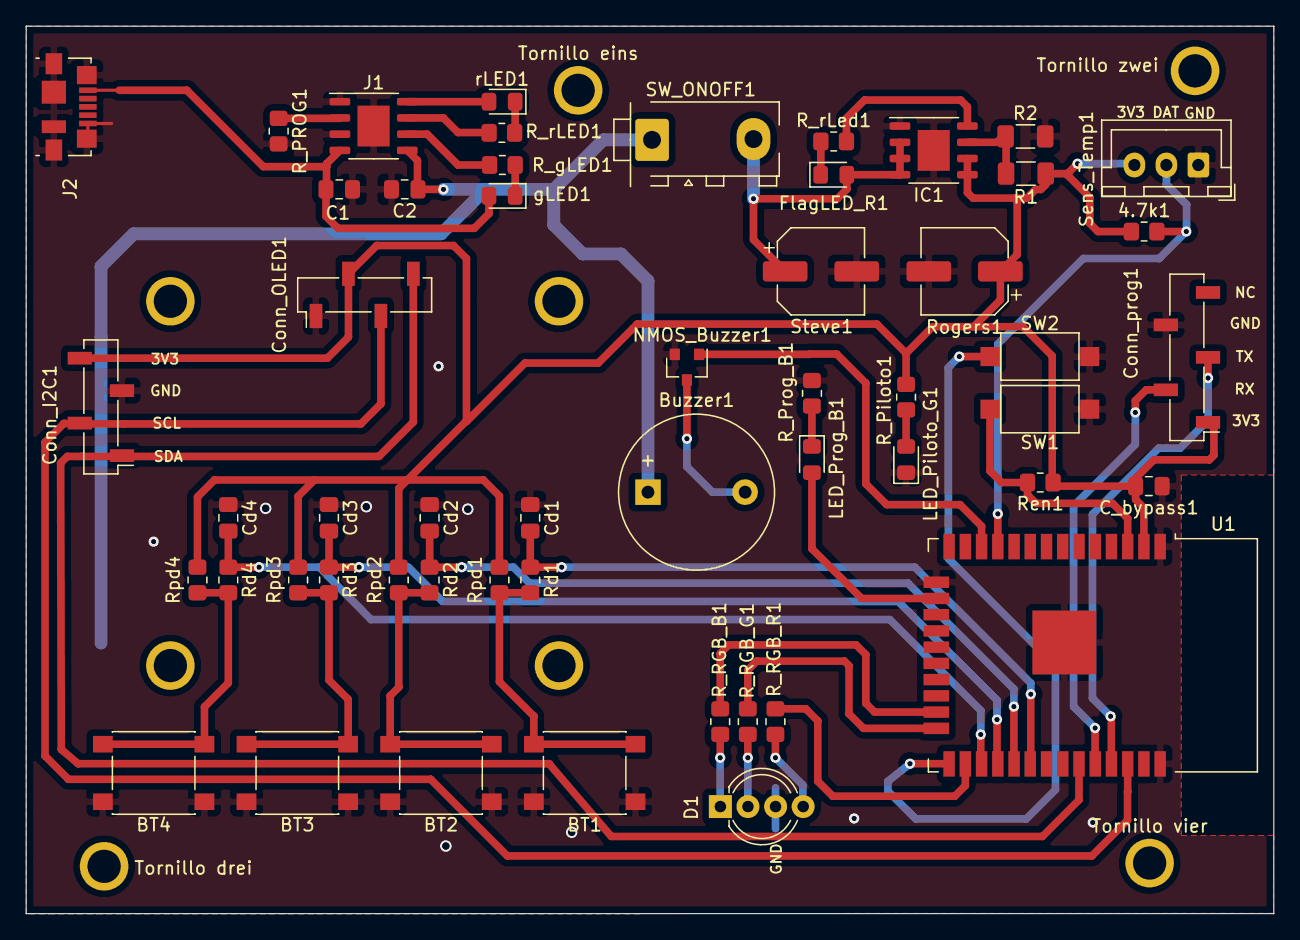
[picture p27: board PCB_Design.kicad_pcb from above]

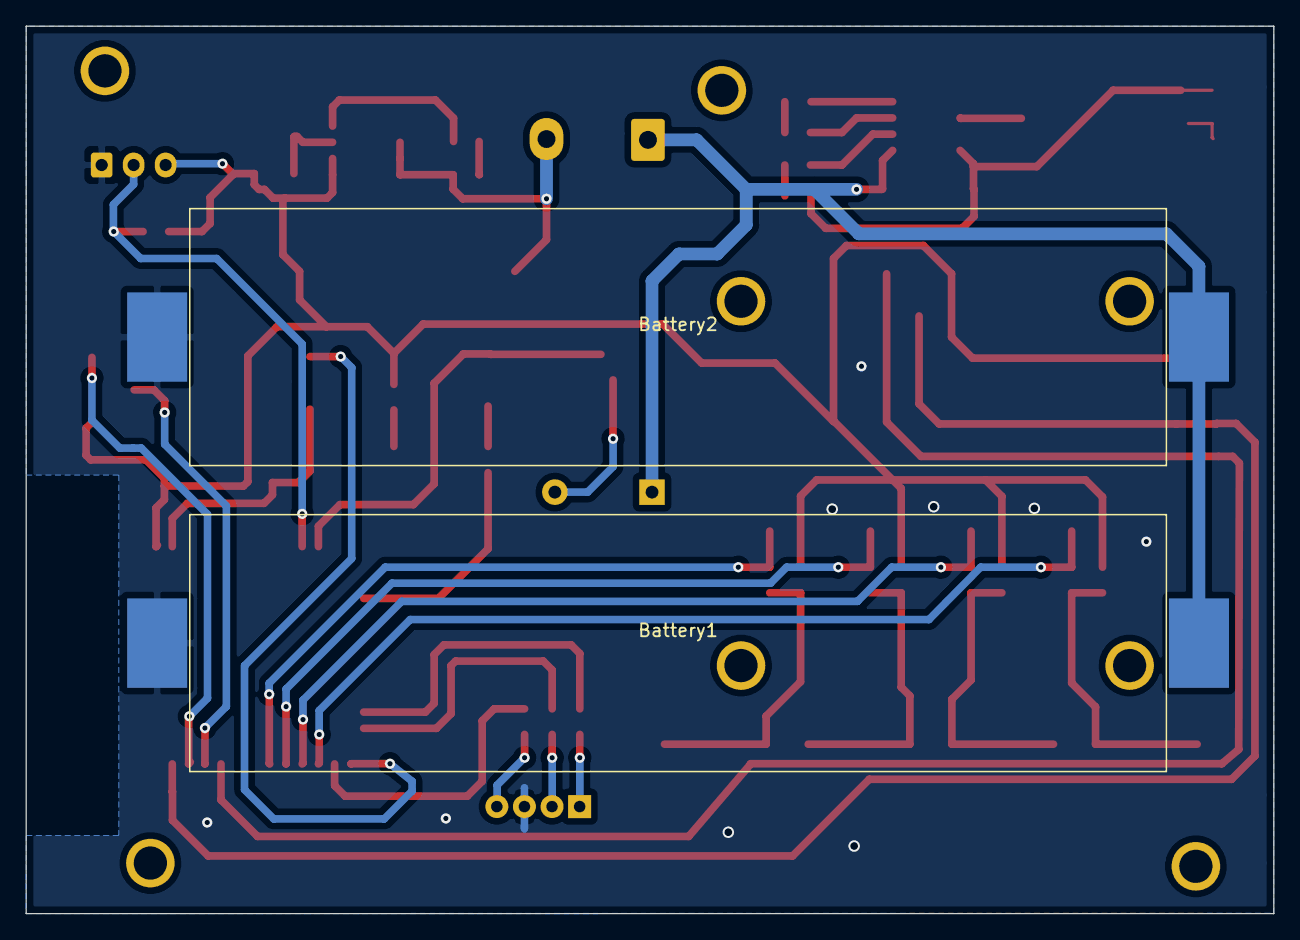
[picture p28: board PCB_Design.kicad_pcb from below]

Board: 2 copper layers, 97.6 x 69.4 mm, 59 parts (2 on the bottom side), 40 nets.

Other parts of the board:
Tornillo drei: MountingHole_2.2mm_M2_DIN965_Pad
Tornillo eins: MountingHole_2.2mm_M2_DIN965_Pad
Tornillo vier: MountingHole_2.2mm_M2_DIN965_Pad
Tornillo zwei: MountingHole_2.2mm_M2_DIN965_Pad

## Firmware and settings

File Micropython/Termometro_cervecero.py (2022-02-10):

from machine import Pin, I2C, PWM
import sh1106
import time
import math
import onewire, ds18x20
from GUI import GUI


def hi_c(pin):
    global state
    global gui
    global temp_actual
    global etapa
    time.sleep(0.4)
    state = not state
    if state:
        gui.pagina_operacion(etapa,temp_actual)
    else:
        gui.pagina_perfil_temp(temp_config)

def hi_u(pin):
    global state
    global paso_etapa
    global etapa
    global alarma
    global t_paso
    time.sleep(0.4)
    if not state:
        if config_index < 4:
            temp_config[config_index] += 1
            gui.update_temp(config_index,temp_config[config_index],True)
        else:
            tiempo_config[config_index-4] += 1
            gui.update_tiempo(config_index-4,tiempo_config[config_index-4],True)
    else:
        if paso_etapa:
            etapa += 1
            paso_etapa = False
            alarma = False
            gui.pagina_operacion(etapa,0)
            t_paso = time.time()

def hi_d(pin):
    global state
    global sonar
    time.sleep(0.4)
    if not state:
        if config_index < 4:
            temp_config[config_index] -= 1
            gui.update_temp(config_index,temp_config[config_index],True)
        else:
            tiempo_config[config_index-4] -= 1
            gui.update_tiempo(config_index-4,tiempo_config[config_index-4],True)
    else:
        sonar = False


def hi_s(pin):
    global config_index
    global gui
    global temp
    global state
    global tiempo
    global init
    time.sleep(0.4)
    if not state:
        if config_index < 4:
            gui.update_temp(config_index,temp_config[config_index],True)
        else:
            gui.update_tiempo(config_index-4,tiempo_config[config_index-4],True)
        config_index = (config_index+1)%9

        if config_index == 4:
            gui.pagina_perfil_tiempo(tiempo_config)
        if config_index == 0:
            gui.pagina_perfil_temp(temp_config)
    else:
        init = True


def medir_temp(sensor,rom):
    global blue
    global red
    global green
    sensor.convert_temp()
    temp = sensor.read_temp(rom)
    blue.duty(temp2RGB(temp,1608,-17.8667))
    red.duty(temp2RGB(temp,0,22.667))
    green.duty(temp2RGB(temp,2221.71,-24.6857))
    return temp

def temp2RGB(temp,x0,m):
    temp = max(min(temp,89.99),20.01)
    return int((temp*m+x0)/2)

state = True #true: normal mode / false: config mode
config_index = 0
config_color = True
init = False
etapa = 0
alarma = False
sonar = False
paso_etapa  = False
t_paso = 0
t_res = 0
t_lev = 0
index_lev = 0
temp_tol = 2

temp_config = [25,25,70,90]
tiempo_config = [0,4,1,2,3,100000]

buzzer = Pin(27, Pin.OUT)
blue = Pin(15, Pin.OUT)
red = Pin(4, Pin.OUT)
green = Pin(2, Pin.OUT)

blue = PWM(blue)
blue.freq(9000)
blue.duty(2**10//2)

red = PWM(red)
red.freq(9000)
red.duty(2**10//2)

green = PWM(green)
green.freq(9000)
green.duty(2**10//2)


buzzer.value(0)
ds_pin = Pin(26)
ds_sensor = ds18x20.DS18X20(onewire.OneWire(ds_pin))
roms = ds_sensor.scan()
rom = roms[0]

i2c = I2C(scl=Pin(22), sda=Pin(21), freq=400000)
display = sh1106.SH1106_I2C(128, 64, i2c)
gui = GUI(display)

gui.pagina_operacion(0,0)


btn_c = Pin(16, Pin.IN)
btn_u = Pin(5, Pin.IN)
btn_d = Pin(17, Pin.IN)
btn_s = Pin(18, Pin.IN)

btn_c.irq(trigger=Pin.IRQ_RISING, handler=hi_c)
btn_u.irq(trigger=Pin.IRQ_RISING, handler=hi_u)
btn_d.irq(trigger=Pin.IRQ_RISING, handler=hi_d)
btn_s.irq(trigger=Pin.IRQ_RISING, handler=hi_s)

temp_actual = ds_sensor.read_temp(rom)

while not init:
    if state:
        temp_actual = medir_temp(ds_sensor,rom)
        gui.update_temp_actual(temp_actual)
        time.sleep(1)
    else:
        if config_index < 4:
            gui.update_temp(config_index,temp_config[config_index],config_color)
        else:
            gui.update_tiempo(config_index-4,tiempo_config[config_index-4],config_color)
        config_color = not config_color
        time.sleep(0.5)

while init:
    if state:
        if etapa == 0:
            etapa += 1
            gui.pagina_operacion(1,medir_temp(ds_sensor,rom))
        elif etapa == 1:
            temp_actual = medir_temp(ds_sensor,rom)
            gui.update_temp_actual(temp_actual)
            if temp_actual > temp_config[0]:
                paso_etapa = True
                alarma = True
        elif etapa == 2:
            temp_actual = medir_temp(ds_sensor,rom)
            gui.update_temp_actual(temp_actual)
            t_res = tiempo_config[0]-(time.time()-t_paso)//60
            gui.update_tiempo_res(t_res)
            paso_etapa = False
            if sonar:
                alarma = abs(temp_config[1]-temp_actual)>temp_tol
            else:
                alarma = False
            if abs(temp_config[1]-temp_actual)<temp_tol:
                sonar = True
            if t_res < 0:
                etapa +=1
                alarma = True
                gui.pagina_operacion(etapa,0)
        elif etapa == 3:
            temp_actual = medir_temp(ds_sensor,rom)
            gui.update_temp_actual(temp_actual)
            paso_etapa = True
            if sonar:
                alarma = abs(temp_config[2]-temp_actual)>temp_tol
            else:
                alarma = False
            if abs(temp_config[2]-temp_actual)<temp_tol:
                sonar = True
        elif etapa == 4:
            temp_actual = medir_temp(ds_sensor,rom)
            gui.update_temp_actual(temp_actual)
            paso_etapa = True
        elif etapa == 5:
            temp_actual = medir_temp(ds_sensor,rom)
            gui.update_temp_actual(temp_actual)
            t_res = tiempo_config[1]-(time.time()-t_paso)//60
            gui.update_tiempo_res(t_res)
            t_lev = (time.time()-t_paso)//60
            paso_etapa = False

            if t_lev > tiempo_config[2+index_lev]:
                alarma = True
                index_lev += 1
            if not sonar:
                alarma = False
                sonar = True
            if t_res < 0:
                etapa +=1
                alarma = True
                gui.pagina_operacion(etapa,0)
        elif etapa == 6:
            alarma = sonar
            temp_actual = medir_temp(ds_sensor,rom)
            gui.update_temp_actual(temp_actual)
            if temp_actual < 20:
                etapa += 1
                gui.pagina_operacion(0,0)
                alarma = True
        else:
            alarma = sonar



        if alarma:
            buzzer.value(1)
            time.sleep(0.5)
            buzzer.value(0)
            time.sleep(0.5)


    else:
        if config_index < 4:
            gui.update_temp(config_index,temp_config[config_index],config_color)
        else:
            gui.update_tiempo(config_index-4,tiempo_config[config_index-4],config_color)
        config_color = not config_color
        time.sleep(0.5)

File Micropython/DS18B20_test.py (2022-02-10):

import machine, onewire, ds18x20, time
from machine import Pin, I2C
import sh1106
from GUI import GUI


ds_pin = machine.Pin(26)
ds_sensor = ds18x20.DS18X20(onewire.OneWire(ds_pin))
i2c = I2C(scl=Pin(22), sda=Pin(21), freq=400000)
display = sh1106.SH1106_I2C(128, 64, i2c)
gui = GUI(display)


roms = ds_sensor.scan()
gui.pagina_operacion(0)

while True:
  ds_sensor.convert_temp()
  time.sleep_ms(500)
  gui.update_temp_actual(ds_sensor.read_temp(roms[0]))
  time.sleep(1)

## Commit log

2021-11-16 Creación del archivo de PCB
    [PCB_Design.kicad_pcb, PCB_Design.sch]
2021-11-16 PCB en blanco
    [PCB_Design.sch]
2021-11-18 Esquemático del circuito de carga creado, sin formato
    [PCB_Design.kicad_pcb, PCB_Design.sch]
2021-11-23 Hojas en el esquemático
    Se añadió como hoja independiente el cargador de la batería al esquemático.
    [PCB_Design.sch, batteryCharge.sch, voltageRegulator.sch]
2021-11-24 arreglo estetico de esquematico
    [batteryCharge.sch, voltageRegulator.sch]
2021-11-25 Creación de la hoja de regulación de tensión
    [PCB_Design.sch, VoltageRegulator.sch, batteryCharge.sch]
2021-11-30 Programación por UART-Botones
    Se añadieron los botones con el circuito de debouncing, un botón de enable para la esp32 y los pines para la programacion.
    [Button.sch, PCB_Design.sch, VoltageRegulator.sch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]
2021-12-01 Partialy finished schematic
    [PCB_Design.sch, VoltageRegulator.sch, batteryCharge.sch]
2021-12-02 huellas agregadas
    [Button.sch, PCB_Design.kicad_pcb, PCB_Design.sch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]
2021-12-04 huellas editadas
    [PCB_Design.kicad_pcb, PCB_Design.sch]
2021-12-07 Cambio del footprint de los porta baterias
    [PCB_Design.kicad_pcb]
2021-12-09 LCD footprint modified
    [PCB_Design.kicad_pcb]
2021-12-09 Falta tetris
    [Button.sch, PCB_Design.kicad_pcb, PCB_Design.sch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]
2021-12-09 Nuevas huellas y un poco más de orden
    [Button.sch, PCB_Design.kicad_pcb, PCB_Design.sch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]
2021-12-09 PCB organizada con casi todo SMD
    [Button.sch, PCB_Design.kicad_pcb, PCB_Design.sch]
2021-12-10 un poco mas de aire
    [PCB_Design.kicad_pcb]
2021-12-11 Caminos de la PCB sin GND
    [Button.sch, PCB_Design.kicad_pcb, PCB_Design.sch]
2021-12-11 PCB finalizada
    [PCB_Design.kicad_pcb]
2021-12-14 Screws added succesfully
    [PCB_Design.kicad_pcb]
2021-12-15 Creación archivos gerber
    [PCB_Design-B_Cu.gbr, PCB_Design-B_Mask.gbr, PCB_Design-B_Paste.gbr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]
2021-12-15 Creación archivos gerber + tornillos pantalla
    [PCB_Design-B_Cu.gbr, PCB_Design-B_Mask.gbr, PCB_Design-B_Paste.gbr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]
2021-12-16 PCB diseño fianl retocado + lista componentes
    [Button.sch, Lista_componentes.xlsx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]
2022-01-04 PCB final con usb B micro, y modelo 3D de la placa
    [PCB_Design-B_Cu.gbr, PCB_Design-B_Mask.gbr, PCB_Design-B_Paste.gbr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]
2022-01-12 Lista de componentes casi actualizada
    [Lista_componentes.xlsx]
2022-01-12 Lista de componentes actualizada
    [Lista_componentes.xlsx]
2022-01-13 PCB terminada
    [Button.sch, Lista_componentes.xlsx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]
2022-01-20 nueva placa a prueba de la novena
    [Button.sch, Lista_componentes.xlsx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]
2022-01-21 Actualización última compra en mactrónica
    [Lista_componentes.xlsx]
2022-01-21 Actualización con precios de las baterías
    [Lista_componentes.xlsx]
2022-01-22 Lista de componentes y precios terminada
    [Lista_componentes.xlsx]
2022-04-15 Schematic was created
